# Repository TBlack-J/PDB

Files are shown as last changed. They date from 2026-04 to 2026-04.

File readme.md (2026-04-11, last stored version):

# Project Manas: Custom-Power-Distribution-Board



A custom high current Power Distribution Board (PDB) designed specifically for a differential drive robot. This board takes a raw battery input and cleanly steps it down into three isolated, logic level power rails (5V, 3.3V, 1.8V) while actively monitoring system wide power consumption in real time.

## Board Renders



## Key Features
* **Active Power Monitoring:** Integrated INA219 High side current and voltage monitor. Measures total current across a shunt resistor and reports data back to the microcontroller using I2C (SDA/SCL).
* **5V/3.3V Rail:** Used TPS54302 step down Buck Converter. Tuned for <10mV ripple using a LC filter. Isolates power for 3.3V logic and sensors
* **1.8V Rail:** Derived from the 3.3V rail using AP2112K-1.8 low dropout regulator (LDO) for sensitive components.
* **Mechanical Realiability:** 2-layer design with top and bottom ground planes for electromagnetic shielding, via stitched thermal relief, dedicated mounting holes for robot chassis.

## System architecture and Calculations
The buck converters were mathematically tuned to achieve an output voltage ripple of under `~10mV`

* **Input Voltage ($V_{in}$):** 12V (Battery)
* **Switching Frequency ($f_{sw}$):** 400kHz
* **Internal Reference Voltage ($V_{ref}$):** 0.596V

### 1. The 5V Rail

#### A. Voltage Step-Down
The TPS54302 steps down the 12V input by rapidly switching on and off. The exact 5V output is maintained by a resistor divider network ($R_3$ and $R_4$) that feeds a scaled down voltage back to the chip's internal reference.
* **Calculated Output ($V_{out}$):**
  $$V_{out} = V_{ref} \cdot \left(1 + \frac{R_{top}}{R_{bot}}\right)$$
  $$V_{out} = 0.596\text{V} \cdot \left(1 + \frac{100\text{k}\Omega}{13.3\text{k}\Omega}\right) \approx \mathbf{5.07\text{V}}$$

#### B. Stage 1: Main LC Filter
The primary inductor ($L_3 = 10\mu\text{H}$) and bulk capacitor ($C_4 = 22\mu\text{F}$) absorb the violent switching pulses to create a stable DC voltage with a slight ripple.
* **Inductor Ripple Current ($\Delta I_L$):**
  $$\Delta I_L = \frac{V_{out} \cdot (V_{in} - V_{out})}{V_{in} \cdot f_{sw} \cdot L_3}$$
  $$\Delta I_L = \frac{5 \cdot (12 - 5)}{12 \cdot 400000 \cdot 10\times 10^{-6}} = \mathbf{0.729\text{A}}$$
* **Stage 1 Voltage Ripple ($\Delta V_{out1}$):**
  $$\Delta V_{out1} = \frac{\Delta I_L}{8 \cdot f_{sw} \cdot C_4}$$
  $$\Delta V_{out1} = \frac{0.729}{8 \cdot 400000 \cdot 22\times 10^{-6}} \approx \mathbf{10.3\text{mV}}$$

#### C. Stage 2: Pi-Filter
To prevent the 10.3mV ripple from interfering with logic thresholds, a secondary low pass filter ($L_2$ Ferrite Bead + $C_5$ $10\mu\text{F}$ Capacitor) physically blocks high frequency switching harmonics.
* **Filter Attenuation Factor ($A$) at 400kHz ($L_{ferrite} \approx 1\mu\text{H}$):**
  $$A = \frac{1}{(2\pi \cdot f_{sw})^2 \cdot L_{ferrite} \cdot C_5}$$
  $$A = \frac{1}{(2\pi \cdot 400000)^2 \cdot 1\times 10^{-6} \cdot 10\times 10^{-6}} \approx \mathbf{0.0158}$$
* **Final 5V Output Ripple ($\Delta V_{total}$):**
  $$\Delta V_{total} = \Delta V_{out1} \cdot A$$
  $$\Delta V_{total} = 10.3\text{mV} \cdot 0.0158 \approx \mathbf{0.16\text{mV}}$$

---

### 2. The 3.3V Sensor Rail

#### A. Voltage Step-Down (Feedback Network)
Similar to the 5V rail, the 3.3V rail uses a distinct resistor divider ($R_5$ and $R_6$) to program the output.
* **Calculated Output ($V_{out}$):**
  $$V_{out} = 0.596\text{V} \cdot \left(1 + \frac{100\text{k}\Omega}{22.1\text{k}\Omega}\right) \approx \mathbf{3.29\text{V}}$$

#### B. Stage 1: Main LC Filter
Tuned specifically for the lower voltage drop, utilizing $L_4 = 6.8\mu\text{H}$ and $C_8 = 22\mu\text{F}$.
* **Inductor Ripple Current ($\Delta I_L$):**
  $$\Delta I_L = \frac{3.3 \cdot (12 - 3.3)}{12 \cdot 400000 \cdot 6.8\times 10^{-6}} = \mathbf{0.879\text{A}}$$
* **Stage 1 Voltage Ripple ($\Delta V_{out1}$):**
  $$\Delta V_{out1} = \frac{0.879}{8 \cdot 400000 \cdot 22\times 10^{-6}} \approx \mathbf{12.5\text{mV}}$$

#### C. Stage 2: Pi-Filter
Utilizing an identical Pi-Filter configuration ($L_5$ Ferrite Bead + $C_9$ $10\mu\text{F}$ Capacitor), the attenuation factor remains identical ($A = 0.0158$).
* **Final 3.3V Output Ripple ($\Delta V_{total}$):**
  $$\Delta V_{total} = 12.5\text{mV} \cdot 0.0158 \approx \mathbf{0.20\text{mV}}$$

---

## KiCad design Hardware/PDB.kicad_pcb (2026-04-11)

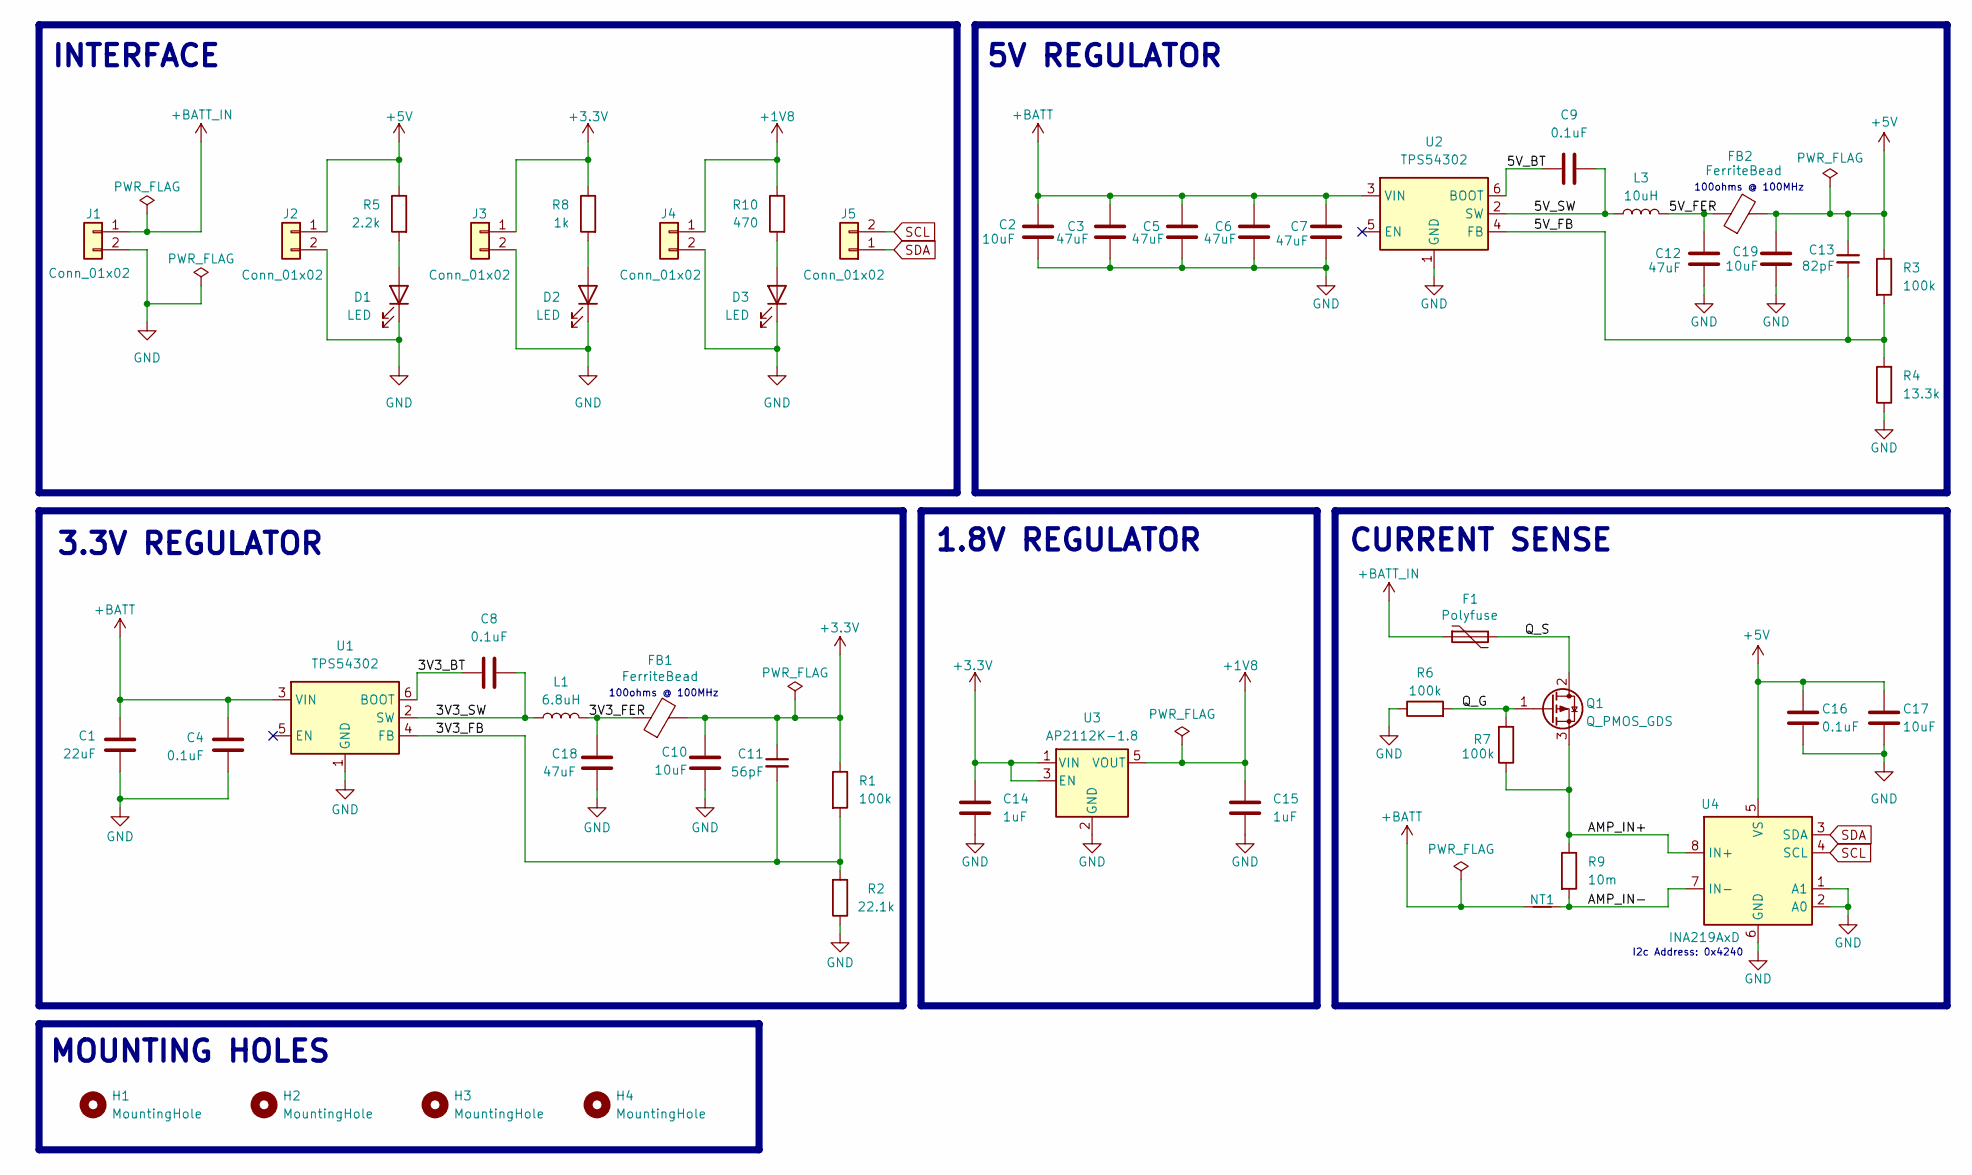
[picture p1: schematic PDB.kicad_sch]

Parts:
C1: 22uF; C_1206_3216Metric
C2, C10, C17, C19: 10uF; C_1206_3216Metric
C3, C5, C6, C7, C12, C18: 47uF; C_1206_3216Metric
C4, C8, C9, C16: 0.1uF; C_0805_2012Metric
C11: 56pF; C_0603_1608Metric
C13: 82pF; C_0603_1608Metric
C14, C15: 1uF; C_0805_2012Metric
D1, D2, D3: LED; LED_0805_2012Metric
F1: Polyfuse; Fuse_1812_4532Metric
FB1, FB2: FerriteBead; L_0805_2012Metric; MPN MPZ2012S101AT000
H1, H2, H3, H4: MountingHole; MountingHole_2.1mm
J1, J2, J3, J4, J5: Conn_01x02; PinHeader_1x02_P2.54mm_Vertical
L1: 6.8uH; L_6.3x6.3_H3
L3: 10uH; L_6.3x6.3_H3
NT1: NetTie_2; NetTie-2_SMD_Pad0.6mm
Q1: Q_PMOS_GDS; SOIC-8_3.9x4.9mm_P1.27mm
R1, R3, R6, R7: 100k; R_0805_2012Metric
R2: 22.1k; R_0805_2012Metric
R4: 13.3k; R_0805_2012Metric
R5: 2.2k; R_0805_2012Metric
R8: 1k; R_0805_2012Metric
R9: 10m; R_2512_6332Metric
R10: 470; R_0805_2012Metric
U1, U2: TPS54302; SOT-23-6
U3: AP2112K-1.8; SOT-23-5
U4: INA219AxD; SOIC-8_3.9x4.9mm_P1.27mm

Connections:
+1V8: C15.2, J4.1, R10.1, U3.5 (VOUT)
+3.3V: C10.1, C11.1, C14.1, FB1.2, J3.1, R1.1, R8.1, U3.1 (VIN), U3.3 (EN)
+5V: C13.1, C16.2, C17.2, C19.1, FB2.2, J2.1, R3.1, R5.1, U4.5 (VS)
+BATT: C1.1, C2.1, C3.1, C4.2, C5.1, C6.1, C7.1, NT1.1, U1.3 (VIN), U2.3 (VIN)
+BATT_IN: F1.1, J1.1
/3V3_BT: C8.1, U1.6 (BOOT)
/3V3_FB: C11.2, R1.2, R2.2, U1.4 (FB)
/3V3_SW: C8.2, L1.1, U1.2 (SW)
/5V_BT: C9.1, U2.6 (BOOT)
/5V_FB: C13.2, R3.2, R4.2, U2.4 (FB)
/5V_SW: C9.2, L3.1, U2.2 (SW)
/AMP_IN+: Q1.3 (S), R7.1, R9.1, U4.8 (IN+)
/AMP_IN-: NT1.2, R9.2, U4.7 (IN-)
/Q_G: Q1.1 (G), R6.2, R7.2
/Q_S: F1.2, Q1.2 (D)
GND: C1.2, C2.2, C3.2, C4.1, C5.2, C6.2, C7.2, C10.2, C12.2, C14.2, C15.1, C16.1, C17.1, C18.2, C19.2, D1.1 (K), D2.1 (K), D3.1 (K), J1.2, J2.2, J3.2, J4.2, R2.1, R4.1, R6.1, U1.1 (GND), U2.1 (GND), U3.2 (GND), U4.1 (A1), U4.2 (A0), U4.6 (GND)
unnamed: C12.1, FB2.1, L3.2
unnamed: C18.1, FB1.1, L1.2
unnamed: D1.2 (A), R5.2
unnamed: D2.2 (A), R8.2
unnamed: D3.2 (A), R10.2
SCL: J5.2, U4.4 (SCL)
SDA: J5.1, U4.3 (SDA)

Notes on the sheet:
MOUNTING HOLES
INTERFACE
CURRENT SENSE
100ohms @ 100MHz
5V REGULATOR
1.8V REGULATOR
3.3V REGULATOR
I2c Address: 0x4240

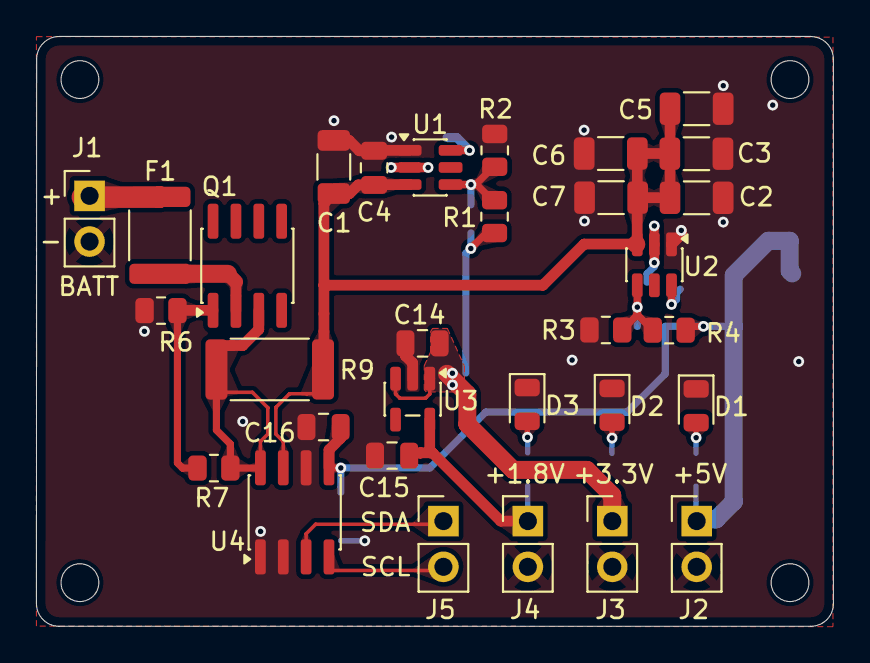
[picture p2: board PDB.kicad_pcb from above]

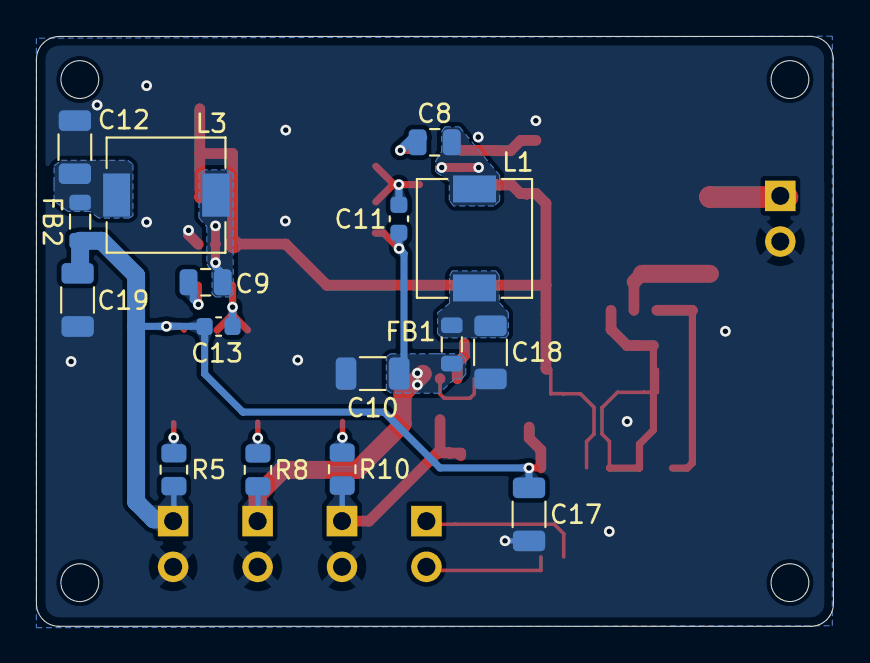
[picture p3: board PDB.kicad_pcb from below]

Board: 2 copper layers, 44.3 x 32.8 mm, 52 parts (16 on the bottom side), 23 nets.

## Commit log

2026-04-11 Updated schematic and PCB
    [BOM.csv, PDB.kicad_pcb, PDB.kicad_sch]
2026-04-11 Added silkscreen labels
    [PDB.kicad_pcb]
2026-04-11 Small fixes
    [PDB.kicad_pcb]
2026-04-11 More small changes
    [PDB.kicad_pcb]
2026-04-11 Even more small changes
    [PDB.kicad_pcb, PDB.kicad_sch]
2026-04-11 More changes
    [BOM.csv, PDB.kicad_pcb, PDB.kicad_sch]
